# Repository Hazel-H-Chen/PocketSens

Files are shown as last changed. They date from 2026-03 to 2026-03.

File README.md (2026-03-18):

# PocketSens Portable Sensor Suite

PocketSens is a portable environmental sensor platform designed to measure environmental and physical data beyond the capabilities of a typical smartphone. The system integrates multiple sensors on a custom four layer PCB and provides real time measurements through a small OLED display and rotary encoder interface.

## Overview

PocketSens is built around an ARM Cortex M0+ SAMD21 microcontroller and communicates with several sensors over an I²C bus. The device collects environmental measurements and displays them directly on the device, allowing users to monitor conditions in real time.

The system is designed as a compact handheld tool capable of measuring atmospheric and environmental parameters in a single portable device. 

## Sensors

The device integrates several sensors including:

* BME680 environmental sensor
  gas, humidity, pressure, temperature
* BMP390 barometric pressure sensor
* MLX90614 infrared temperature sensor
* AS3935 lightning detection sensor

Together these sensors allow the device to measure a wide range of environmental conditions in real time. 

## Hardware

* Custom four layer PCB designed in KiCad
* ARM Cortex M0+ SAMD21 microcontroller
* OLED display for live data output
* Rotary encoder for user interface
* I²C sensor bus architecture

## Features

* Multi sensor environmental monitoring
* Real time data display on OLED screen
* Lightning detection capability
* Infrared temperature sensing
* Compact portable design

## Repository Contents

pcb/
KiCad schematic and PCB layout files

images/
Board photos and layout screenshots

docs/
Additional design notes and documentation

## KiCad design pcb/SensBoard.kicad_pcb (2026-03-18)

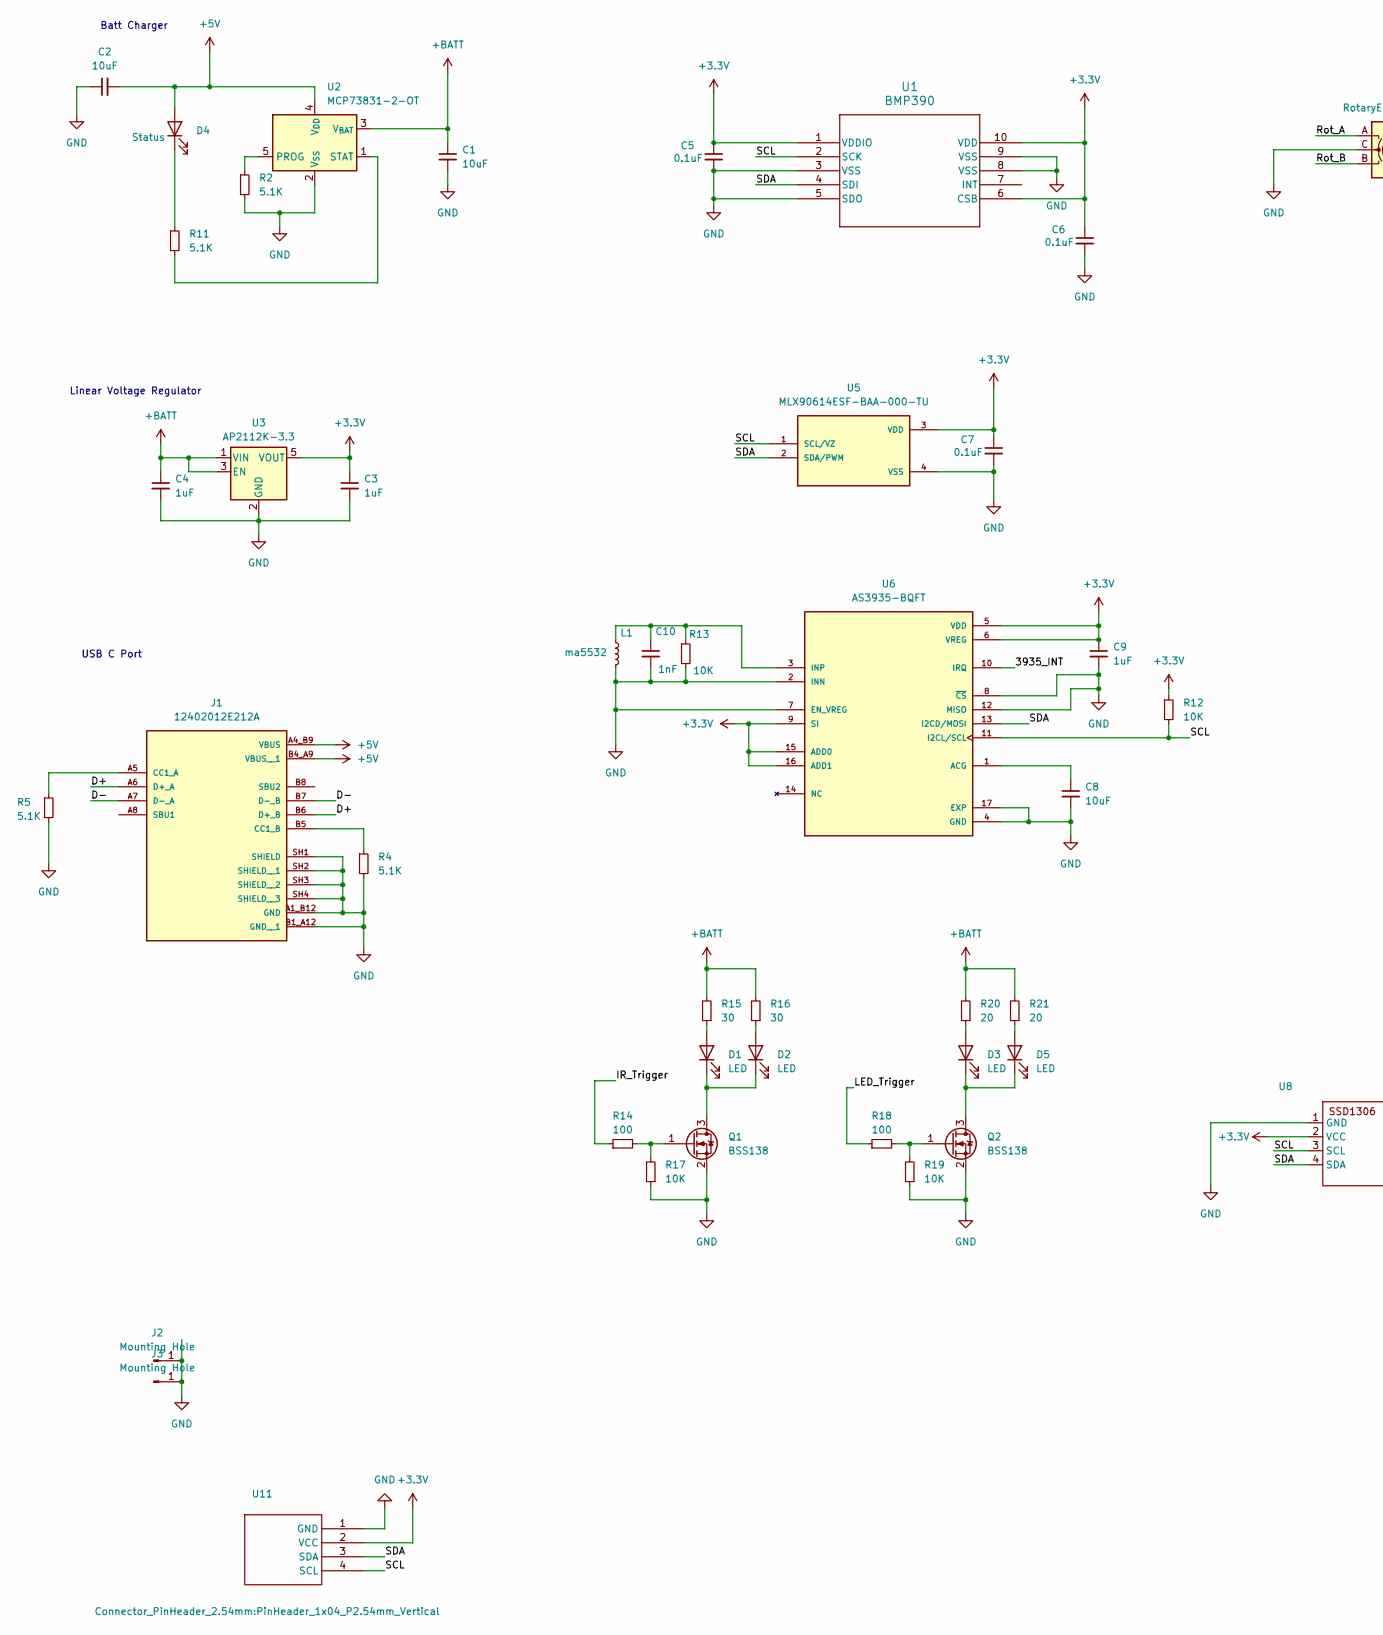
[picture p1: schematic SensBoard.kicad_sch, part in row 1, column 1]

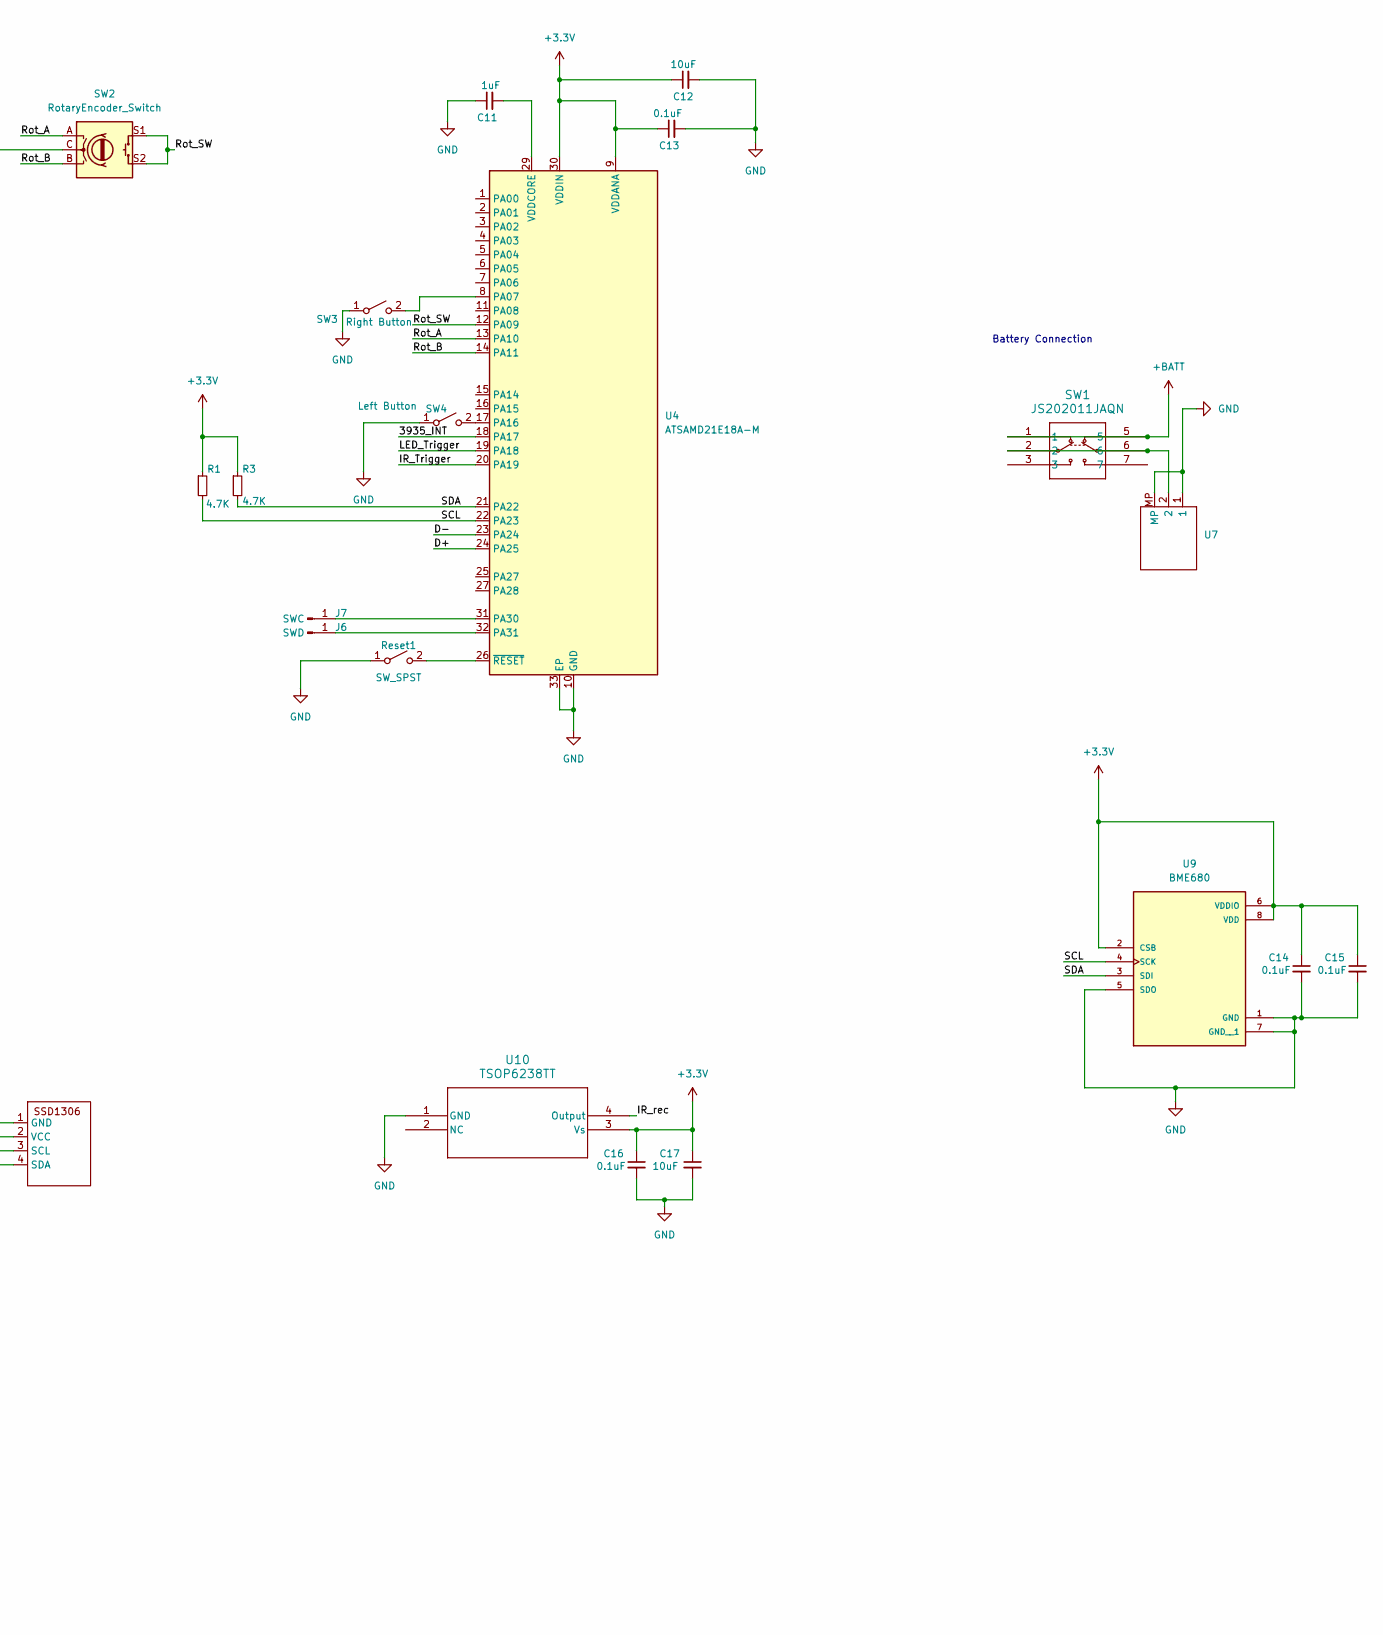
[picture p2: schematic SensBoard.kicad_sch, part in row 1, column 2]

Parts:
C1, C2, C8, C12, C17: 10uF; C_0603_1608Metric
C3, C4, C9, C11: 1uF; C_0603_1608Metric
C5, C6, C7, C13, C14, C15, C16: 0.1uF; C_0603_1608Metric
C10: 1nF; C_0603_1608Metric
D1, D2, D3, D5: LED; LED_PLCC_2835
D4: Status; LED_0603_1608Metric
J1: 12402012E212A; AMPHENOL_12402012E212A; PARTREV 4
J2, J3: Mounting Hole; MountingHole_2.2mm_M2_DIN965_Pad
J6: SWD; PinHeader_1x01_P2.54mm_Vertical
J7: SWC; PinHeader_1x01_P2.54mm_Vertical
L1: ma5532; MA5532-AE
Q1, Q2: BSS138; SOT-23
R1, R3: 4.7K; R_0603_1608Metric
R2, R11: 5.1K; R_0402_1005Metric
R4, R5: 5.1K; R_0603_1608Metric
R12: 10K; R_0402_1005Metric_Pad0.72x0.64mm_HandSolder
R13, R17, R19: 10K; R_0603_1608Metric
R14, R18: 100; R_0603_1608Metric
R15, R16: 30; R_2512_6332Metric
R20, R21: 20; R_0603_1608Metric
Reset1: SW_SPST; SolderJumper-2_P1.3mm_Open_TrianglePad1.0x1.5mm
SW1: JS202011JAQN; JS202011JAQN_CNK
SW2: RotaryEncoder_Switch; RotaryEncoder_Alps_EC11E-Switch_Vertical_H20mm
SW3: Right Button; SW2_KSS341GLFS_CNK
SW4: Left Button; SW2_KSS341GLFS_CNK
U1: BMP390; 10LGA_2X2X0p75_BOS
U2: MCP73831-2-OT; SOT-23-5
U3: AP2112K-3.3; SOT-23-5
U4: ATSAMD21E18A-M; QFN-32-1EP_5x5mm_P0.5mm_EP3.6x3.6mm
U5: MLX90614ESF-BAA-000-TU; TO254P942H425-4; PARTREV 13
U6: AS3935-BQFT; QFN65P400X400X80-17N
U7: JST_PH_S2B-PH-SM4-TB_1x02-1MP_P2.00mm_Horizontal
U8: 128x64OLED
U9: BME680; PSON80P300X300X100-8N; PARTREV 1.9
U10: TSOP6238TT; SOJ_6238TT_VIS-M
U11: PinHeader_1x04_P2.54mm_Vertical

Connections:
+3.3V: C3.1, C5.1, C6.1, C7.1, C9.1, C12.1, C13.1, C14.1, C15.1, C16.1, C17.1, R1.1, R3.1, R12.1, U1.1 (VDDIO), U1.6 (CSB), U1.10 (VDD), U3.5 (VOUT), U4.9 (VDDANA), U4.30 (VDDIN), U5.3 (VDD), U6.5 (VDD), U6.6 (VREG), U6.9 (SI), U6.15 (ADD0), U6.16 (ADD1), U8.2 (VCC), U9.2 (CSB), U9.6 (VDDIO), U9.8 (VDD), U10.3 (Vs), U11.2 (VCC)
+5V: C2.2, D4.2 (A), J1.A4_B9 (VBUS), J1.B4_A9 (VBUS__1), U2.4 (V_{DD})
+BATT: C1.1, C4.1, R15.2, R16.2, R20.2, R21.2, SW1.1, SW1.5, U2.3 (V_{BAT}), U3.1 (VIN), U3.3 (EN)
/3935_INT: U4.18 (PA17), U6.10 (IRQ)
/D+: J1.A6 (D+_A), J1.B6 (D+_B), U4.24 (PA25)
/D-: J1.A7 (D-_A), J1.B7 (D-_B), U4.23 (PA24)
/IR_Trigger: R14.1, U4.20 (PA19)
/IR_rec: U10.4 (Output)
/LED_Trigger: R18.1, U4.19 (PA18)
/Rot_A: SW2.A, U4.13 (PA10)
/Rot_B: SW2.B, U4.14 (PA11)
/Rot_SW: SW2.S1, SW2.S2, U4.12 (PA09)
/SCL: R1.2, R12.2, U1.2 (SCK), U4.22 (PA23), U5.1 (SCL/VZ), U6.11 (I2CL/SCL), U8.3 (SCL), U9.4 (SCK), U11.4 (SCL)
/SDA: R3.2, U1.4 (SDI), U4.21 (PA22), U5.2 (SDA/PWM), U6.13 (I2CD/MOSI), U8.4 (SDA), U9.3 (SDI), U11.3 (SDA)
GND: C1.2, C2.1, C3.2, C4.2, C5.2, C6.2, C7.2, C8.2, C9.2, C10.2, C11.1, C12.2, C13.2, C14.2, C15.2, C16.2, C17.2, J1.A1_B12 (GND), J1.B1_A12 (GND__1), J1.SH1 (SHIELD), J1.SH2 (SHIELD__1), J1.SH3 (SHIELD__2), J1.SH4 (SHIELD__3), J2.1, J3.1, L1.2, Q1.2 (S), Q2.2 (S), R2.2, R4.2, R5.2, R13.2, R17.1, R19.1, Reset1.1 (A), SW2.C, SW3.1 (A), SW4.1 (A), U1.3 (VSS), U1.5 (SDO), U1.8 (VSS), U1.9 (VSS), U2.2 (V_{SS}), U3.2 (GND), U4.10 (GND), U4.28 (GND), U4.33 (EP), U5.4 (VSS), U6.2 (INN), U6.4 (GND), U6.7 (EN_VREG), U6.8 (~CS), U6.12 (MISO), U6.17 (EXP), U7.1, U7.MP, U8.1 (GND), U9.1 (GND), U9.5 (SDO), U9.7 (GND__1), U10.1 (GND), U11.1 (GND)
unnamed: D1.2 (A), R15.1
unnamed: D1.1 (K), D2.1 (K), Q1.3 (D)
unnamed: D2.2 (A), R16.1
unnamed: D3.2 (A), R20.1
unnamed: D3.1 (K), D5.1 (K), Q2.3 (D)
unnamed: D4.1 (K), R11.1
unnamed: D5.2 (A), R21.1
unnamed: J1.A5 (CC1_A), R5.1
unnamed: J1.B5 (CC1_B), R4.1
unnamed: J6.1, U4.32 (PA31)
unnamed: J7.1, U4.31 (PA30)
unnamed: Q1.1 (G), R14.2, R17.2
unnamed: Q2.1 (G), R18.2, R19.2
unnamed: Reset1.2 (B), U4.26 (~RESET)
unnamed: SW1.2, SW1.6, U7.2
unnamed: SW3.2 (B), U4.8 (PA07)
unnamed: SW4.2 (B), U4.17 (PA16)
unnamed: R2.1, U2.5 (PROG)
unnamed: R11.2, U2.1 (STAT)
unnamed: C11.2, U4.29 (VDDCORE)
unnamed: C8.1, U6.1 (ACG)
unnamed: C10.1, L1.1, R13.1, U6.3 (INP)

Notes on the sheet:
Batt Charger
Linear Voltage Regulator
USB C Port
Battery Connection

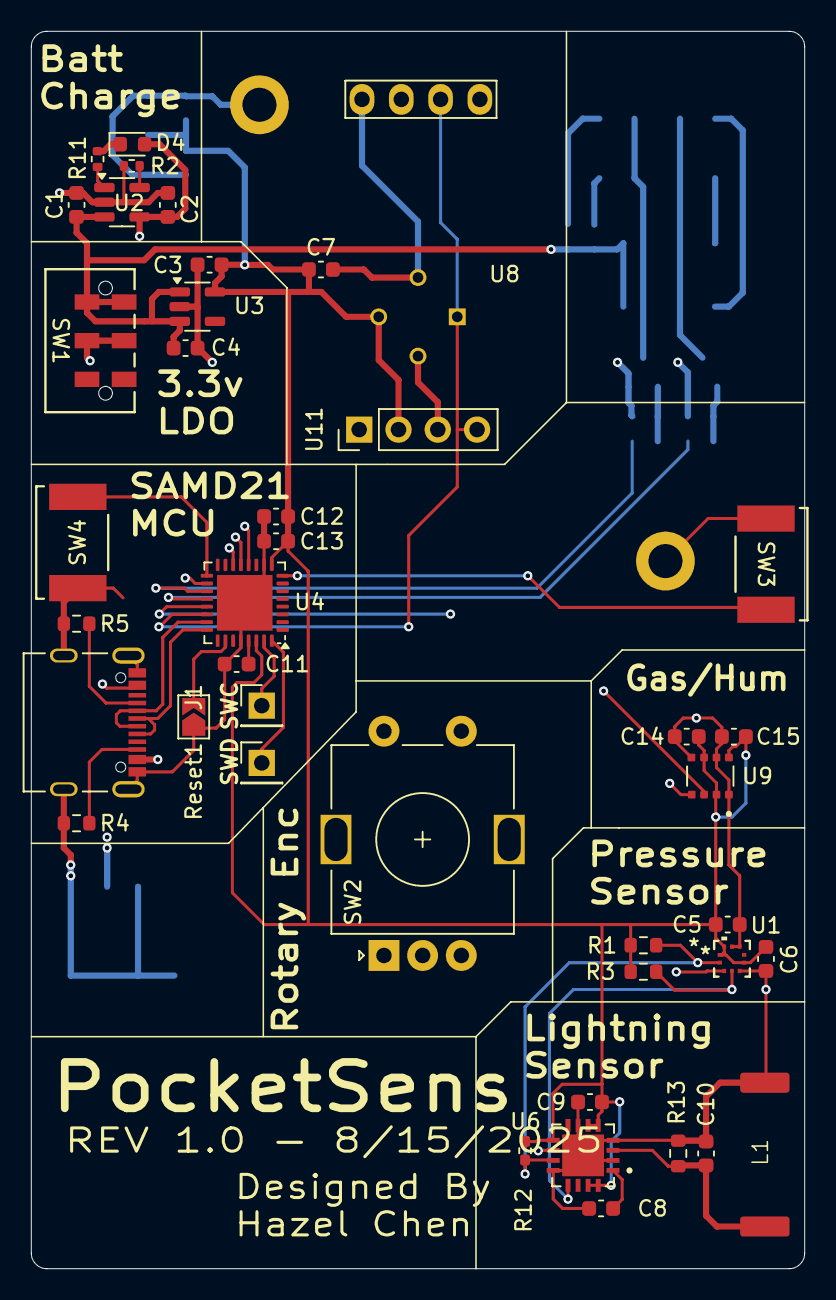
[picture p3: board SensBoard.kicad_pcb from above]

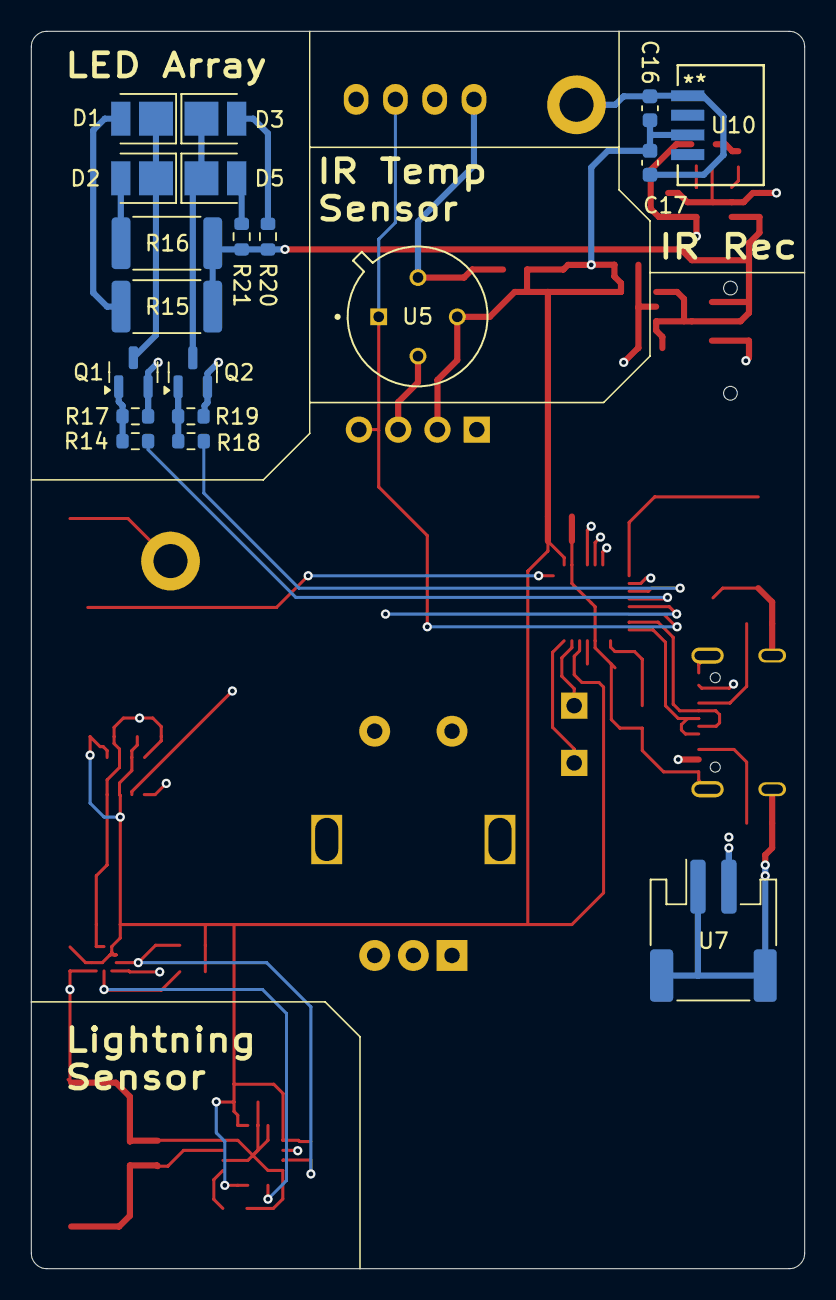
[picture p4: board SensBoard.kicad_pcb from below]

Board: 4 copper layers, 50.0 x 80.0 mm, 62 parts (19 on the bottom side), 36 nets.
